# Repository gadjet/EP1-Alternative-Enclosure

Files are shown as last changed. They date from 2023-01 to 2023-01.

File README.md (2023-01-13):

# EP1-Alternative-Enclosure
An alternative enclosure for the everything presence one sensor

**Please note - 
You may have to cut 1mm off the bottom of the PIR pins to get the case to close completely.**

I wanted to design an enclosure for the EP1 that fully enclosed the mmwave sensor so that no spiders etc. got inside and created false alarms, this means a compromise to the light and temperature sensors but I've tried to allow for these as best I can whilst keeping the case basically spider proof.

The wall mount is a very tight fit into the back piece and you will need to be careful inserting it, the capscrew and nut may not be needed to tighten up the joint but it's there to use if needed.  Insert the ball with the flats adjacent to the arms of the clamp then when inserted twist through 90 degrees.

The STL files for the front, back and mount can be found in the files along with other images of the assembly.

The front and back should be printed standing up with the flat end on the print bed, depending on your printer the back can be printed without supports but the front may need them, I used tree supports in Cura.

The wall mount needs printing with the ball flat on the bed with the wall plate at 90 degrees to the bed.
# Print Orientations
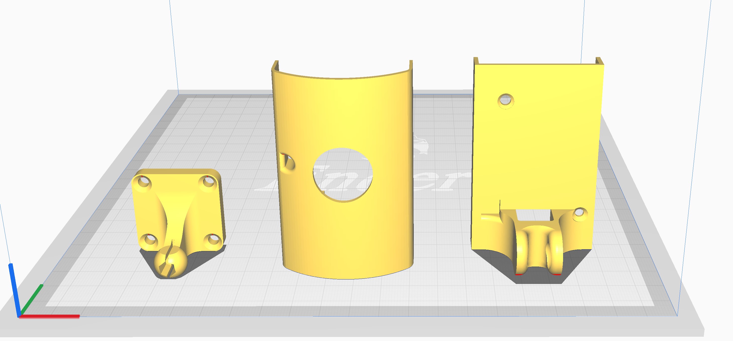
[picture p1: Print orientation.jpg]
Print Orientations


# Some Features
* I used a 180 degree USBC adapter to convert the cable entry from downwards to upwards
* Air flow path for temp sensor
* light tube to allow light to fall on the sensor
* fully adjustable mount
* Enclosure secured with M3 countersunk screws

**Whole Unit**

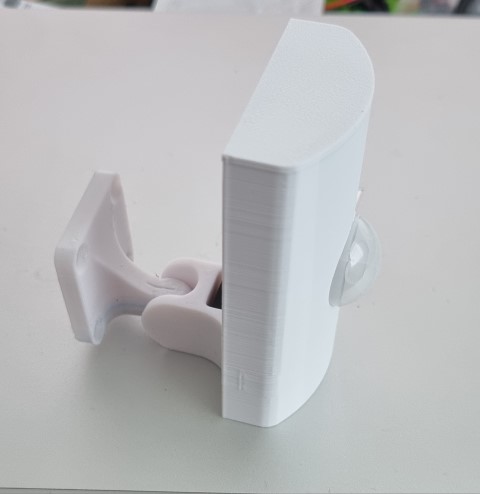
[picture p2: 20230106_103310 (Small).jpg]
Complete unit


**Cable Entry**

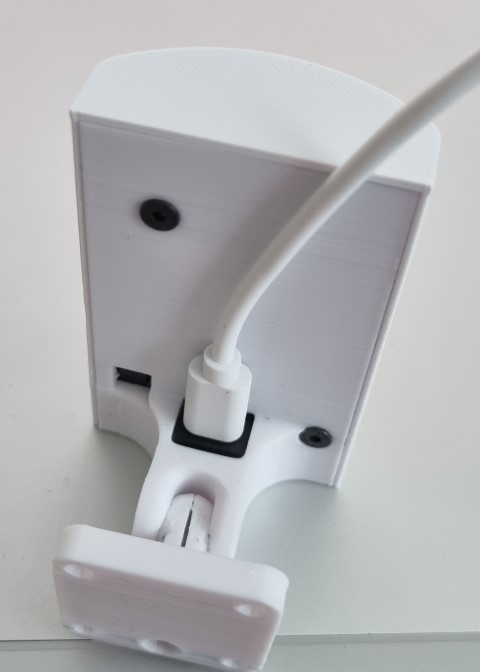
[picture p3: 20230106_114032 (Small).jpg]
Cable Entry


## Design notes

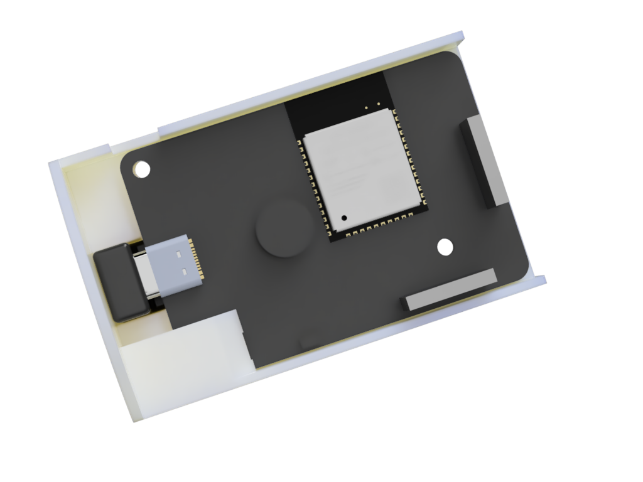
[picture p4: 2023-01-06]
occupancy_sensor_enclosure.png

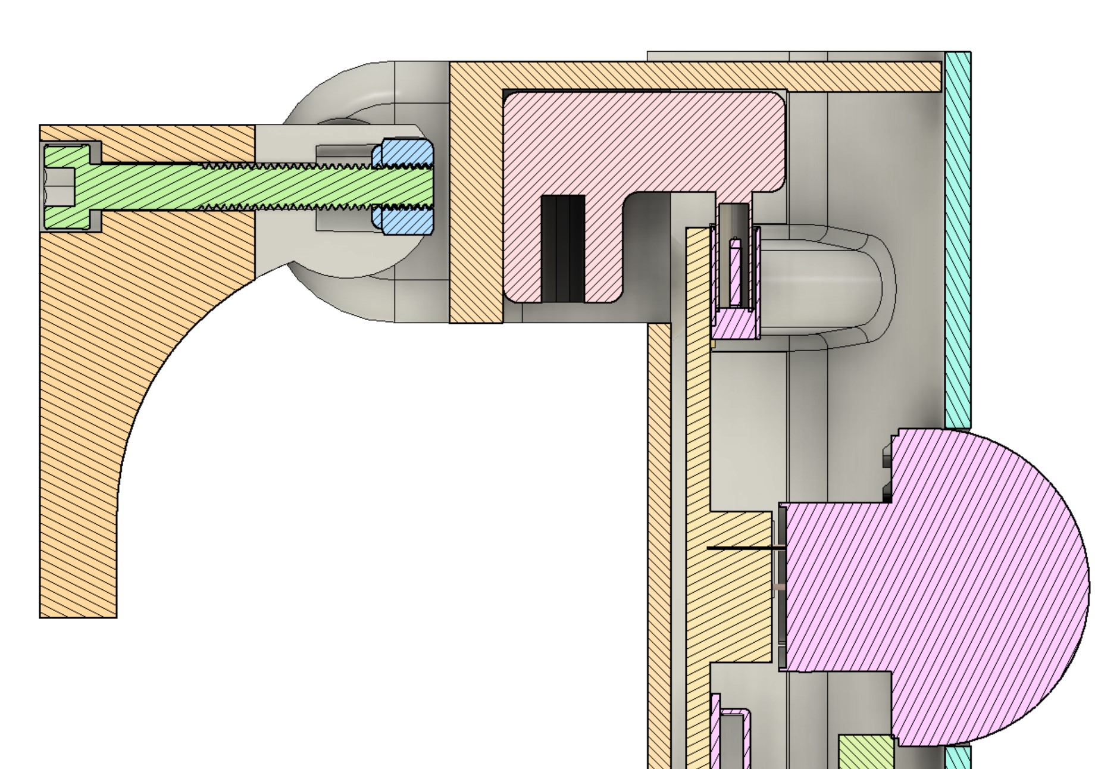
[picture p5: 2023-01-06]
Mount_1_Section.jpg

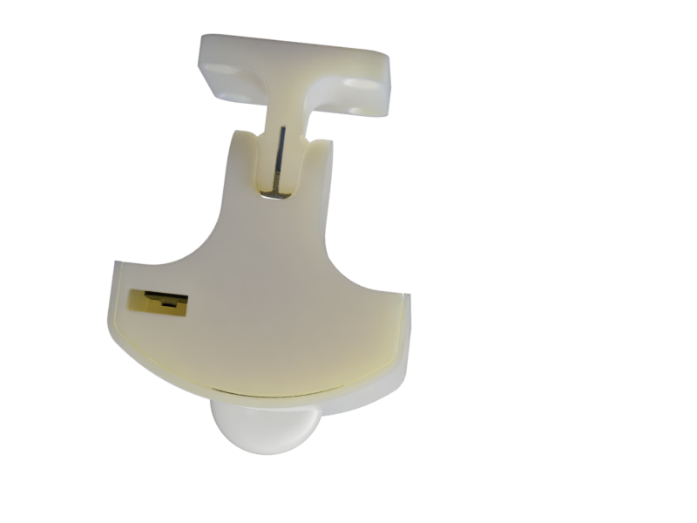
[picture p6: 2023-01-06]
occupancy_sensor_enclosure_Temp_Apature.png

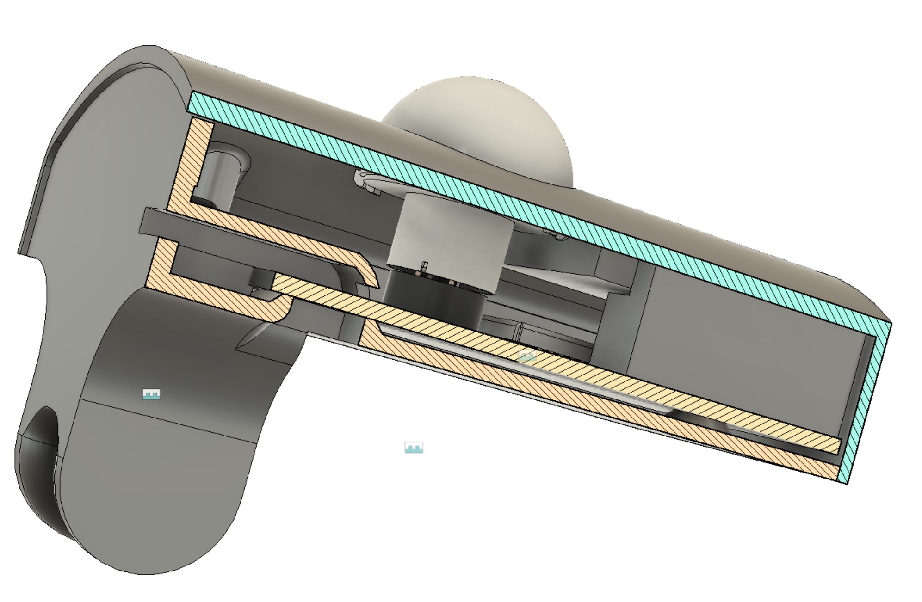
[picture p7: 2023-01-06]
Section Analysis_2.jpg

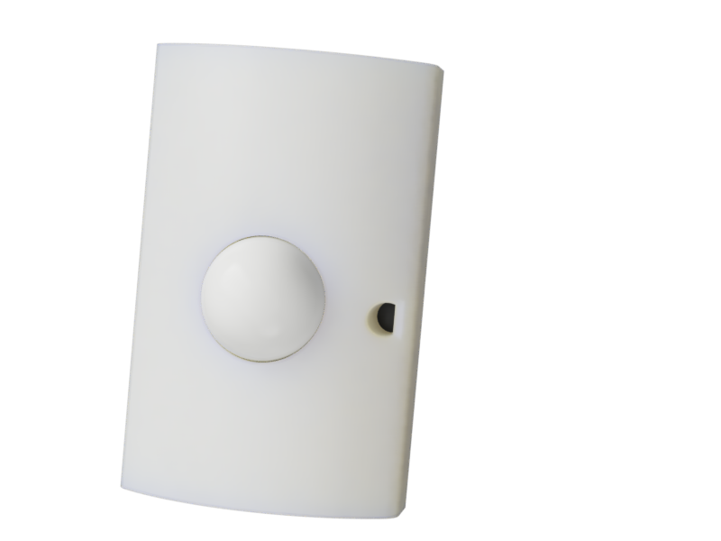
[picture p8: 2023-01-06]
occupancy_sensor_enclosure_Light_Apature.png

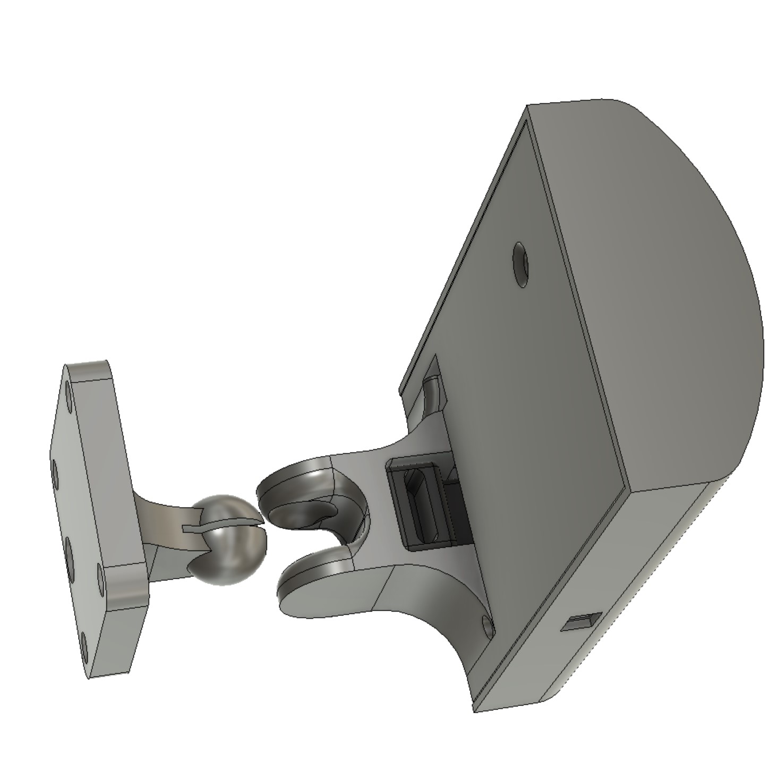
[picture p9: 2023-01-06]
Mount_1.jpg

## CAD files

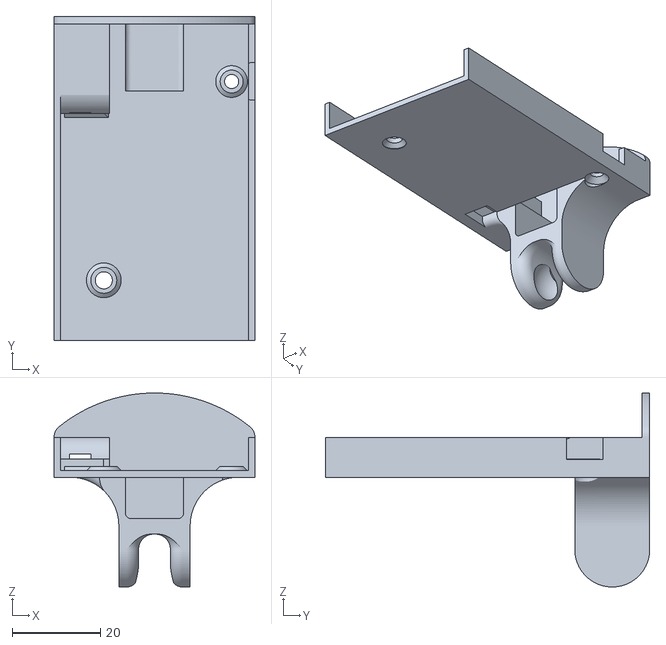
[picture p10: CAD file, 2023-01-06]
Back.stl
45.6 x 73.6 x 44.0

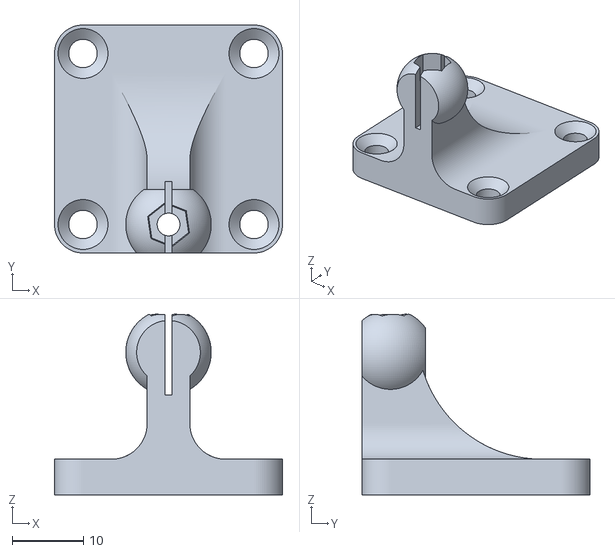
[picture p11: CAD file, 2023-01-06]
Mount.stl
32.0 x 32.0 x 25.4

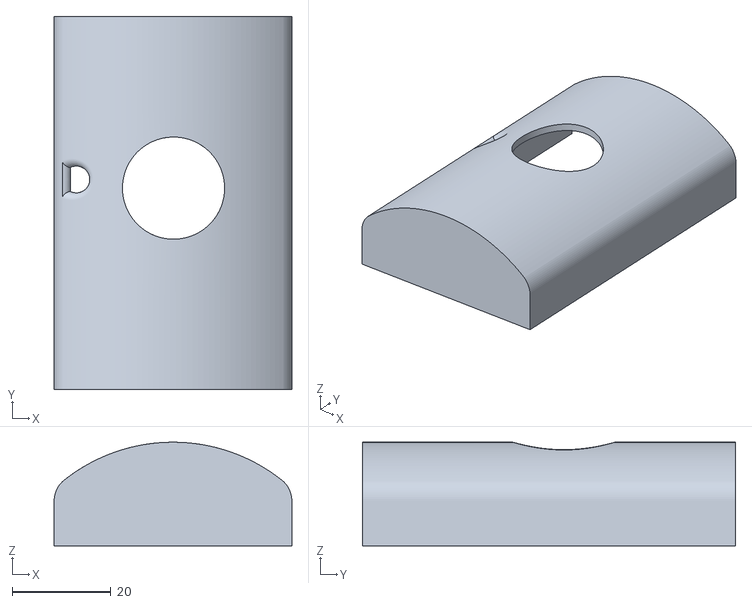
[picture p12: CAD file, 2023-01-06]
Front.stl
48.2 x 75.6 x 21.0
